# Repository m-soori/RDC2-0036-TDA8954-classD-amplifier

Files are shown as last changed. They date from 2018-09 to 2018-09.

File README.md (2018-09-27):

<p><a href="https://static.chipdip.ru/lib/911/DOC003911524.jpg" class="galery">RDC2-0036</a></p>

<p>Модуль RDC2-0036 представляет собой высокопроизводительный усилитель мощности класса D. УНЧ построен на микросхеме TDA8954. Это стереофонический аналоговый чип с цифровым усилителем, предназначенный для работы с 4-омными громкоговорителями мощностью до 210 Вт на канал.RDC2-0036 характеризуется очень низким уровнем шума и низким током покоя.<br>На аналоговый вход усилителя можно подавать как несимметричный так и симметричный (дифференциальный) сигнал.<br> Встроенная система защиты отслеживает: перегрев, перегрузку и короткое замыкание выходов. При наличии одной из вышеперечисленных ошибок усилитель отключается, а после устранения ошибки восстанавливает работу.<br>Для обеспечения высококачественного высокоэффективного усиления звука требуется простой пассивный фильтр демодуляции цифрового сигнала это модуль LCF1. Для управления режимами усилителя необходим дополнительный источник напряжения - 5В. Это напряжение можно получить с помощью модуля RDC1-0013 5V. Для подключения этого модуля на плате установлен разъём (XP5).</p>
<h2>Технические характеристики</h2>
<p>Напряжение питания выходного каскада: двухполярное от ±12.5В до ±37В<br>Количество каналов: 2 x SE, 1 x BTL<br>Сопротивление нагрузки SE: 4-8 Ом<br>Сопротивление нагрузки BTL: 8 Ом<br>Выходная мощность SE: 210 Вт / 4 Ом<br>Выходная мощность BTL: 420 Вт / 8 Ом <br>Коэффициент нелинейных искажений:0.05%<br>КПД с нагрузкой 6Ом: 90%</p>
<p>Схема усилителя с выходными фильтрами и дополнительным источником напряжения - 5В.</p>
<p><a href="https://static.chipdip.ru/kits/9000493152/RDC2-0036_full_sch.png" class="galery">Схема</a></p>
<p>Блок-схема усилителя с выходными фильтрами.</p>
<p><a href="https://static.chipdip.ru/kits/9000493153/RDC2-0040_block.png" class="galery">Блок-Схема</a></p>
<p>Подробную инструкцию по включению и конфигурации усилителя можно найти в разделе «Документы».</p>
<p>Это открытый проект! Лицензия, под которой он распространяется – <a href="https://creativecommons.org/licenses/by-sa/3.0/">Creative Commons - Attribution - Share Alike license</a>.</p>

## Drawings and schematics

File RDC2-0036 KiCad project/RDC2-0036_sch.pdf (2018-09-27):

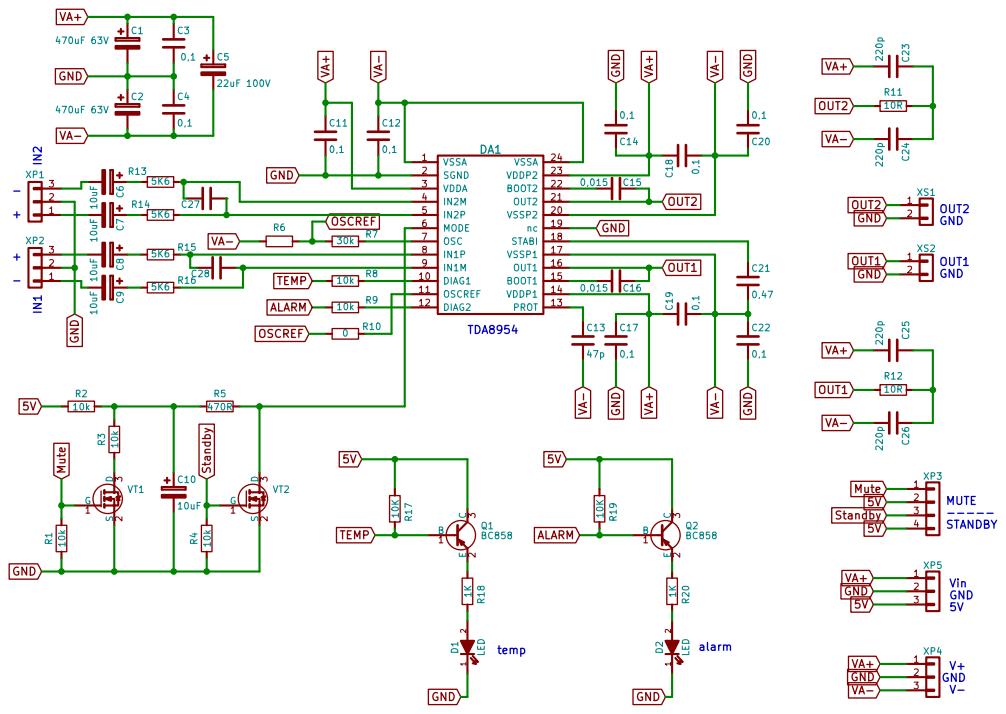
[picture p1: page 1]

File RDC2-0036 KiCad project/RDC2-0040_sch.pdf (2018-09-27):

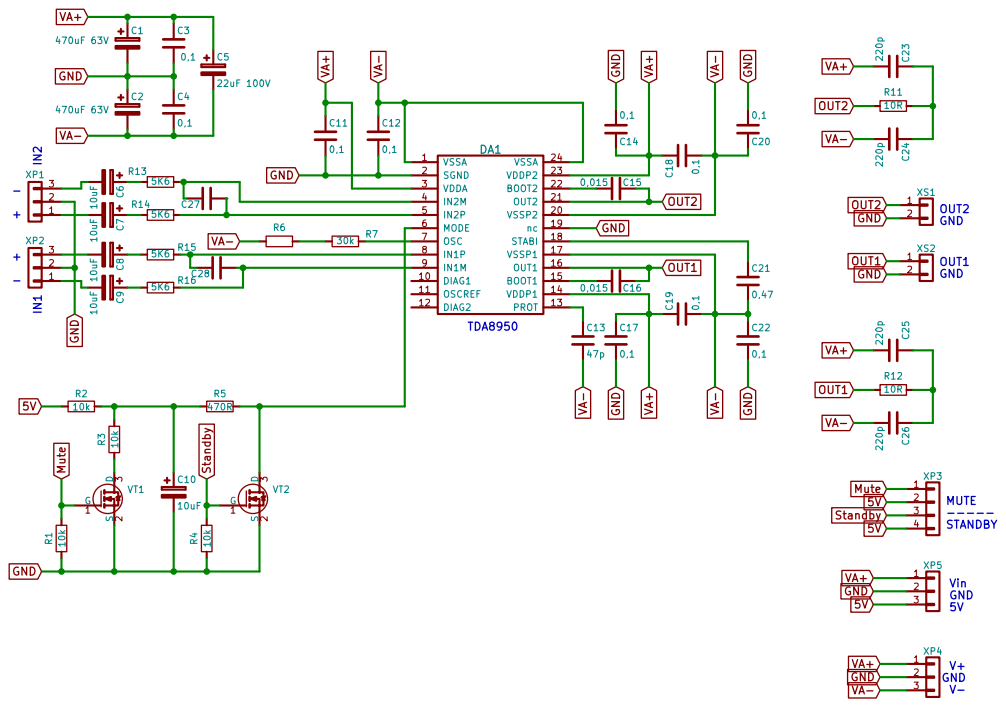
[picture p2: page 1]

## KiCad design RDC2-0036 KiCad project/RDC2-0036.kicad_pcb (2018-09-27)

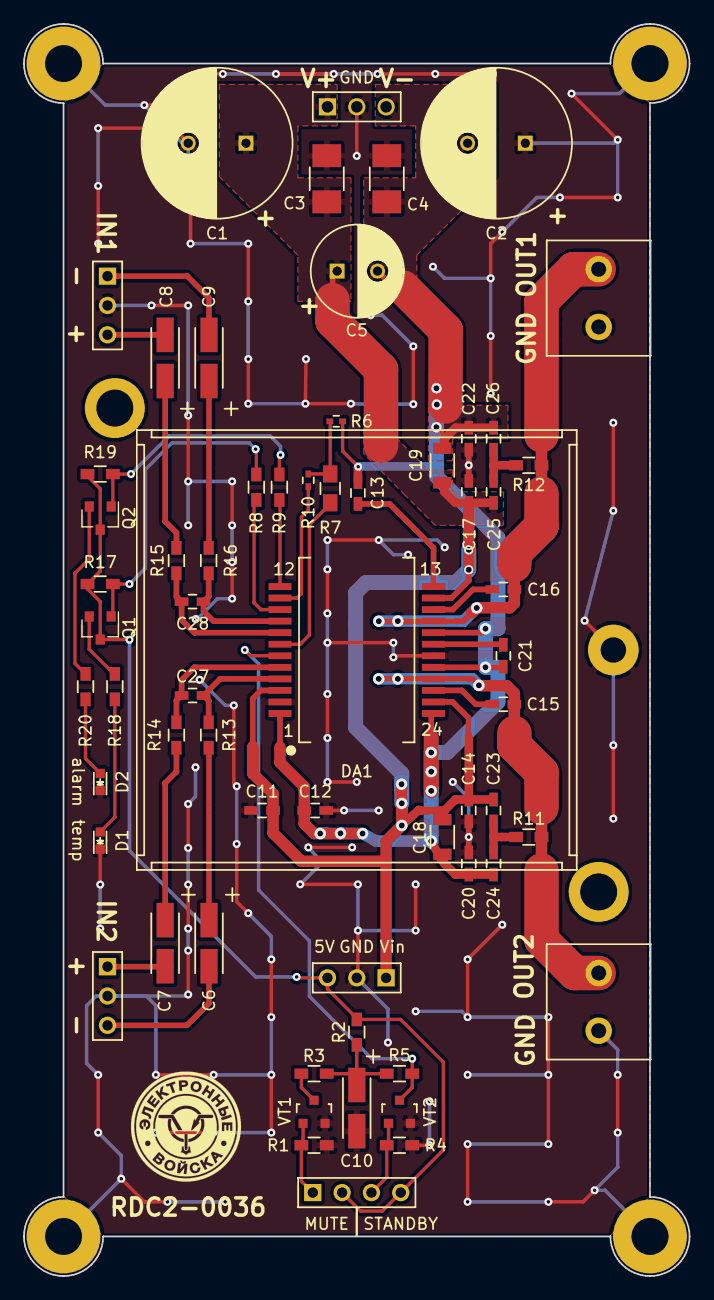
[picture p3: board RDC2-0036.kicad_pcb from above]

Board: 2 copper layers, 57.7 x 108.5 mm, 63 parts (0 on the bottom side), 40 nets.

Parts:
C1, C2: CP; C_Radial_D13_L21_P5
C3, C4: C; C_1210_HandSoldering
C5: CP; C_Radial_D8_L11.5_P3.5
C6, C7, C8, C9, C10: CP; TantalC_SizeA_EIA-3216_HandSoldering_mm
C11, C12, C13, C14, C15, C16, C17, C20, C21, C22, C23, C24, C25, C26, C27, C28: C; C_0603_HandSoldering
C18, C19: C; C_1206
D1, D2: LED; LED_0603
DA1: TDA8954; HSOP24
HeatSink: Heatsink_37x37mm_SpringFixation
Q1, Q2: BC858; SOT-23
R1, R2, R3, R4, R5, R8, R9, R11, R12: R; R_0603_HandSoldering
R6, R10: R; C_0402
R7: R; C_0805_HandSoldering
R13, R14, R15, R16: 5K6; R_0603_HandSoldering
R17, R19: 10K; R_0603_HandSoldering
R18, R20: 1K; R_0603_HandSoldering
VT1, VT2: BSS138; SOT-23_mm
XP1, XP2, XP4, XP5: CONN_01X03; Pin_Header_Straight_1x03_mm
XP3: CONN_01X04; Pin_Header_Straight_1x04_mm
XS1, XS2: CONN_01X02; Clem_2Pos_P5

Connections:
5V: Q1.3, Q2.3, R2.2, R17.1, R19.1, XP3.2, XP3.4, XP5.3
ALARM: Q2.1, R9.1, R19.2
GND: C1.2, C2.1, C3.2, C4.1, C10.2, C11.2, C12.2, C14.2, C17.2, C20.2, C22.2, D1.1, D2.1, DA1.2, DA1.19, R1.2, R4.2, VT1.2, VT2.2, XP1.2, XP2.2, XP4.2, XP5.2, XS1.2, XS2.2
Mute: R1.1, VT1.1, XP3.1
unnamed: C6.1, R13.1
unnamed: C6.2, XP1.3
unnamed: C7.1, R14.1
unnamed: C7.2, XP1.1
unnamed: C8.1, R15.1
unnamed: C8.2, XP2.3
unnamed: C9.1, R16.1
unnamed: C9.2, XP2.1
unnamed: C10.1, R2.1, R3.1, R5.2
unnamed: C13.1, DA1.13
unnamed: C15.2, DA1.22
unnamed: C16.2, DA1.15
unnamed: C21.1, DA1.18
unnamed: C23.1, C24.1, R11.2
unnamed: C25.1, C26.1, R12.2
unnamed: C27.1, DA1.4, R13.2
unnamed: C27.2, DA1.5, R14.2
unnamed: C28.1, DA1.8, R15.2
unnamed: C28.2, DA1.9, R16.2
unnamed: D1.2, R18.2
unnamed: D2.2, R20.2
unnamed: DA1.6, R5.1, VT2.3
unnamed: DA1.7, R7.2
unnamed: DA1.10, R8.2
unnamed: DA1.11, R10.2
unnamed: DA1.12, R9.2
unnamed: Q1.2, R18.1
unnamed: Q2.2, R20.1
unnamed: R3.2, VT1.3
OSCREF: R6.2, R7.1, R10.1
OUT1: C16.1, DA1.16, R12.1, XS2.1
OUT2: C15.1, DA1.21, R11.1, XS1.1
Standby: R4.1, VT2.1, XP3.3
TEMP: Q1.1, R8.1, R17.2
VA+: C1.1, C3.1, C5.1, C11.1, C14.1, C17.1, C18.1, C19.1, C23.2, C25.2, DA1.3, DA1.14, DA1.23, XP4.1, XP5.1
VA-: C2.2, C4.2, C5.2, C12.1, C13.2, C18.2, C19.2, C20.1, C21.2, C22.1, C24.2, C26.2, DA1.1, DA1.17, DA1.20, DA1.24, R6.1, XP4.3

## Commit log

2018-09-27 KiCad project
    [RDC2-0036.kicad_pcb, RDC2-0036.sch, RDC2-0040.sch]
2018-09-27 Gerber files
    [RDC2-0036-B.Cu.gbr, RDC2-0036-B.Mask.gbr, RDC2-0036-B.SilkS.gbr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]
